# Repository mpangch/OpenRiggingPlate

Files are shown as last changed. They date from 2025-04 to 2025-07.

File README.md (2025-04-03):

# Aluminum Rigging Plate

This repository provides detailed instructions, files, and Finite Element Analysis (FEA) results for manufacturing  the OpenRiggingPlate - a **7075-T6 Aluminium, Hard Anodized Rigging Plate** designed for various rigging applications.

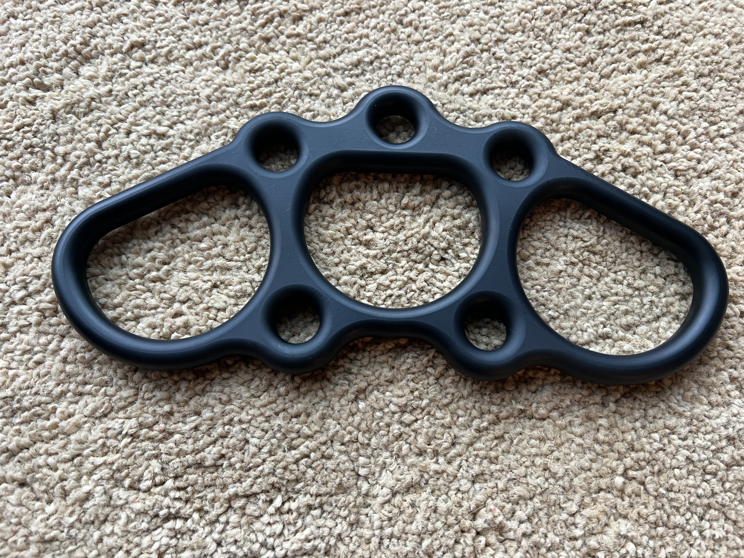
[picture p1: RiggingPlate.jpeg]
OpenRiggingPlate


---

## 📂 Project Files

- **3D Model STEP file**: [`riggingplate-14mar2024.step`](riggingplate-14mar2024.step)  
  *(Ready to upload to CNC services)*

- **SolidWorks Source File**: [`riggingplate-14mar2024.sldprt`](riggingplate-14mar2024.sldprt)  
  *(Modify or customize the design)*

- **Manufacturing Notes PDF**: [`riggingplate-14mar2024-manufacturingnotes.pdf`](riggingplate-14mar2024-manufacturingnotes.pdf)  
  *(Detailed anodizing instructions included—upload this PDF to your machining service.)*

- **Finite Element Analysis**: Refer to the provided `FEA Analysis` folder for detailed results and loading conditions.

---

## 📌 Design Specifications

| Property | Specification |
|---|---|
| **Dimensions** | 235.58 × 111.9 × 12 mm |
| **Material** | Aluminum 7075-T6 (**Do NOT substitute with 6061, as it WILL fail**) |
| **Volume** | 92,450.06 mm³ |
| **Surface Finish**  | CNC machining to **Ra1.6 or better**; hand polishing preferred |
| **Coating** | Hardcoat Anodizing Type III (Default: Black, other colors optional) |
| **Tolerances** | ISO 2768 medium |

---

## 🛠️ How to Manufacture

Follow these step-by-step instructions to have this rigging plate professionally CNC machined:

### **Step 1: Review Files**
- Download all provided files, especially the `.STEP` file for manufacturing and the PDF for anodizing guidelines.

### **Step 2: Choose a CNC Machining Service**
Recommended machining providers:
- [Protolabs](https://www.protolabs.com/)
- [JLCPCB](https://jlcpcb.com/)
- [PCBWay](https://www.pcbway.com/)
- [Xometry](https://www.xometry.com/)
- [Fictiv](https://www.fictiv.com/)

### **Step 3: Upload Files**
- Create an account and log in to your chosen machining service.
- Upload the provided STEP file: `riggingplate-14mar2024.step`.
- **Important:** Upload the PDF file `riggingplate-14mar2024-manufacturingnotes.pdf` with detailed manufacturing and anodizing instructions.

### **Step 4: Specify Material**
- Select **Aluminum 7075-T6** explicitly (critical for safety—6061 WILL fail under load).

### **Step 5: Define Surface Finish**
- Request CNC machining to a minimum surface roughness of **Ra1.6 or better**.
- Specify additional **hand polishing** for a smoother, superior finish.

### **Step 6: Specify Anodizing**
- Select **Type III Hardcoat Anodizing**.
- Default color: **Black** (other colors optional based on preference).
- **Important:** Clearly communicate hanger positions as shown in the provided PDF to minimize visible marks.

### **Step 7: Include Special Instructions**
Copy and paste the following note into the manufacturing special instructions:

> "Please carefully follow the instructions in the provided PDF file (`riggingplate-14mar2024-manufacturingnotes.pdf`) to minimize anodization marks from hanging, restricting marks only to the indicated areas."

### **Step 8: Order & Delivery**
- Confirm all details and submit your order.

---

## 📈 Finite Element Analysis (FEA)

FEA has been thoroughly conducted. The design passed static structural analyses using ANSYS software with remote displacement, allowing rotation about the Z-axis (in and out of page) to simulate realistic load conditions.

### FEA Test Cases and Loading Directions

Refer to the image below to understand each test scenario clearly:

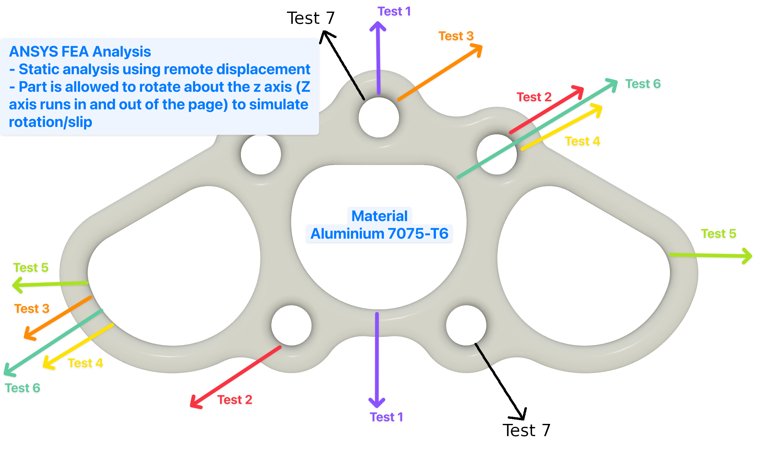
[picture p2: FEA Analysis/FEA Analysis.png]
FEA Analysis


**Minimum Breaking Strength (MBS) Results:**

| Test Case | Direction | Breaking Strength (lbf) |
|---|---|---|
| 1 | Vertical | 2697.7 |
| 2 | Angled horizontal | 2384.5 |
| 3 | Angled horizontal | 4768.8 |
| 4 | Angled horizontal | 2222.5 |
| 5 | Horizontal | 2810.1 |
| 6 | Angled horizontal | 3372.1 |
| 7 | Angled downward | 3034.9 |

Detailed FEA results are available in the `FEA Analysis` folder.

---

## 🚧 Important Notes

- **Material Integrity**: Strict adherence to **7075-T6 aluminum** is required for structural safety. Using weaker materials like 6061 will result in structural failure.
- **Anodizing Hangers**: Carefully follow the instructions in the provided PDF to minimize cosmetic defects from the anodizing process.

---

## 🔧 Modifying the Design

If you wish to customize or adapt the design for specific needs, use the provided SolidWorks source file:

- [`riggingplate-14mar2024.sldprt`](riggingplate-14mar2024.sldprt)

This file allows you to easily modify dimensions, hole positions, or structural features using SolidWorks software.

---

## 📧 Contact

Please open an issue or a pull request on GitHub if you find any errors or have suggestions for improvement.

Happy rigging!

---

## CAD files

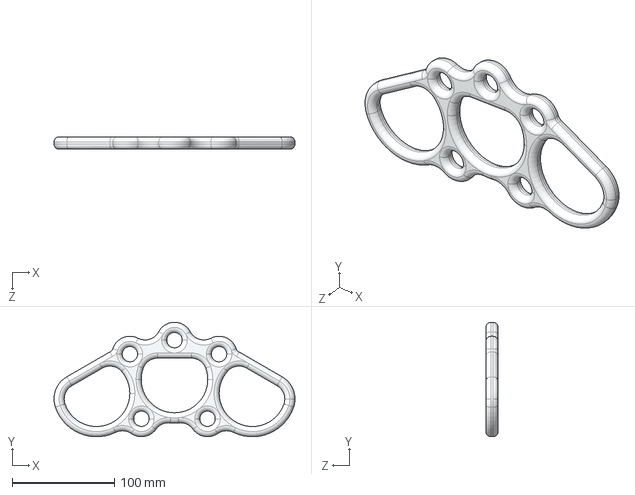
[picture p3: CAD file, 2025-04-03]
riggingplate-14mar2024.step
235.6 x 111.9 x 12.0 mm

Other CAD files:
riggingplate-14mar2024.sldprt

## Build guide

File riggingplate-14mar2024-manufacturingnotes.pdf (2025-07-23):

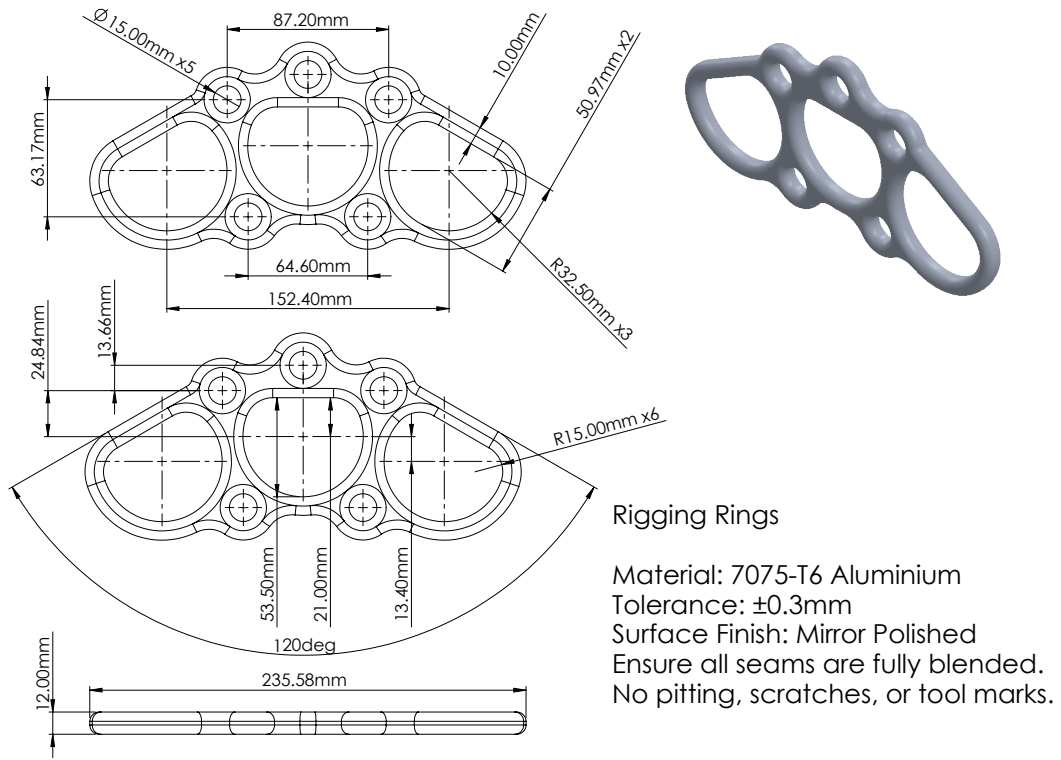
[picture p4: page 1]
120deg

Rigging Rings
Material: 7075-T6 Aluminium
Tolerance: ±0.3mm
Surface Finish: Mirror Polished
Ensure all seams are fully blended.
No pitting, scratches, or tool marks.

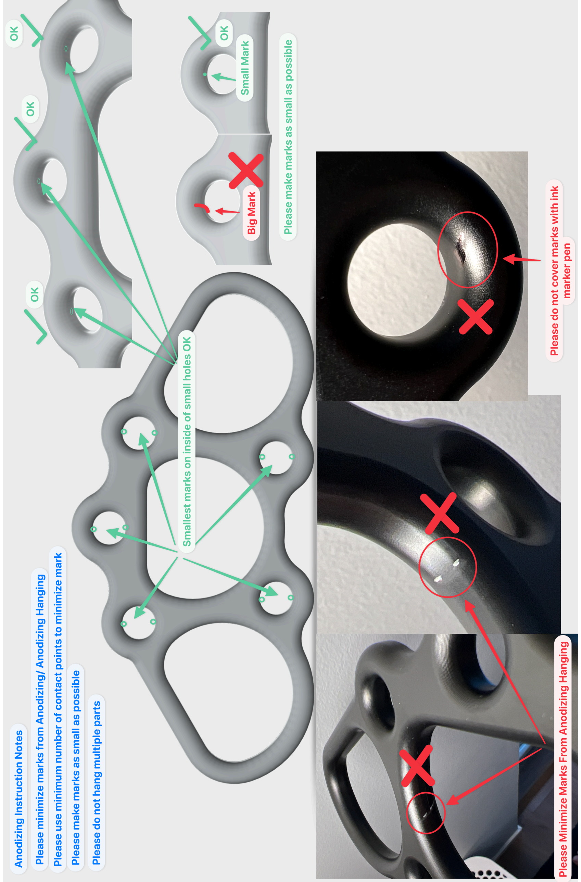
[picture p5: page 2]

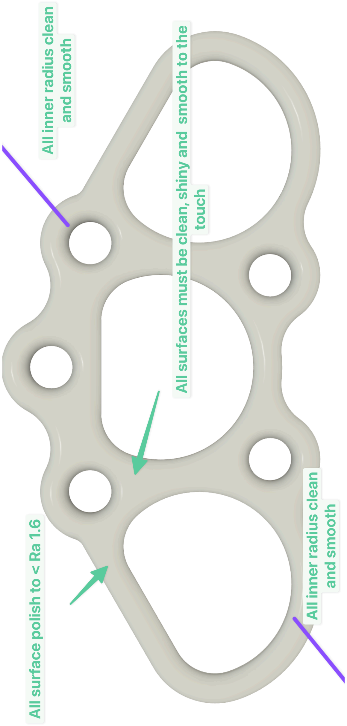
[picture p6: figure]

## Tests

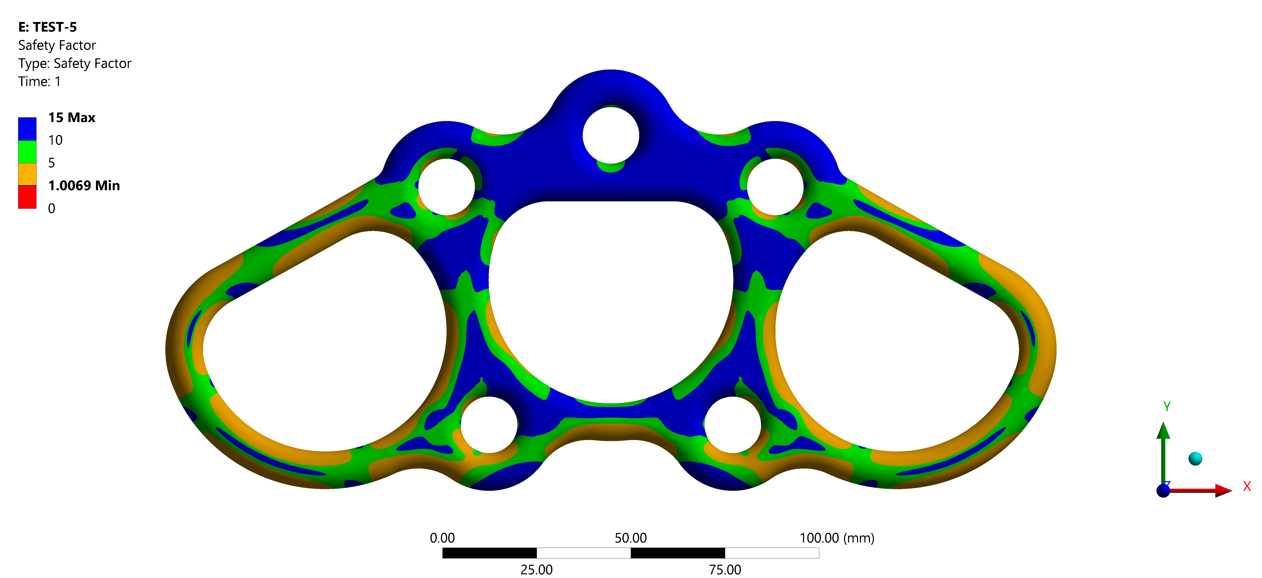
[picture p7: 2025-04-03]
FEA Analysis/Test 5 (2810.1 lbf)/Safety Factor.png

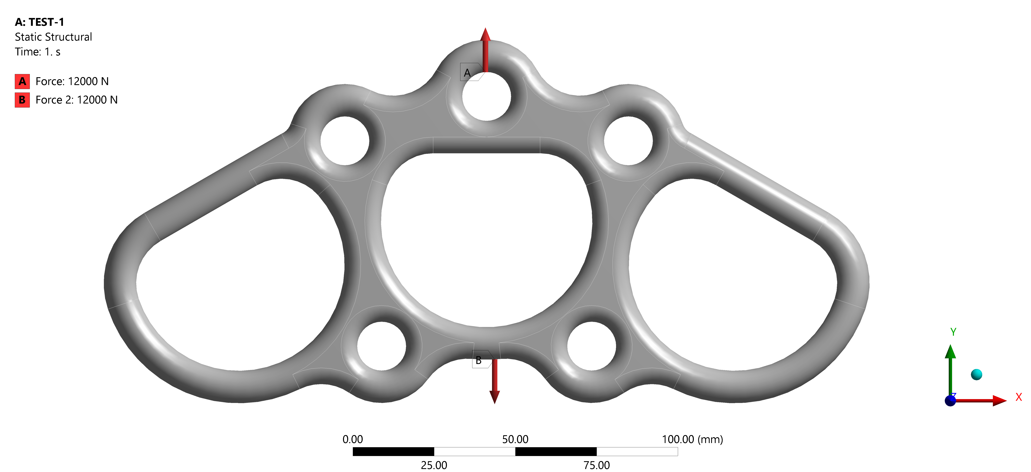
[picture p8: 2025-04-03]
FEA Analysis/Test 1 (2697.7 lbf)/Boundary Conditions.png

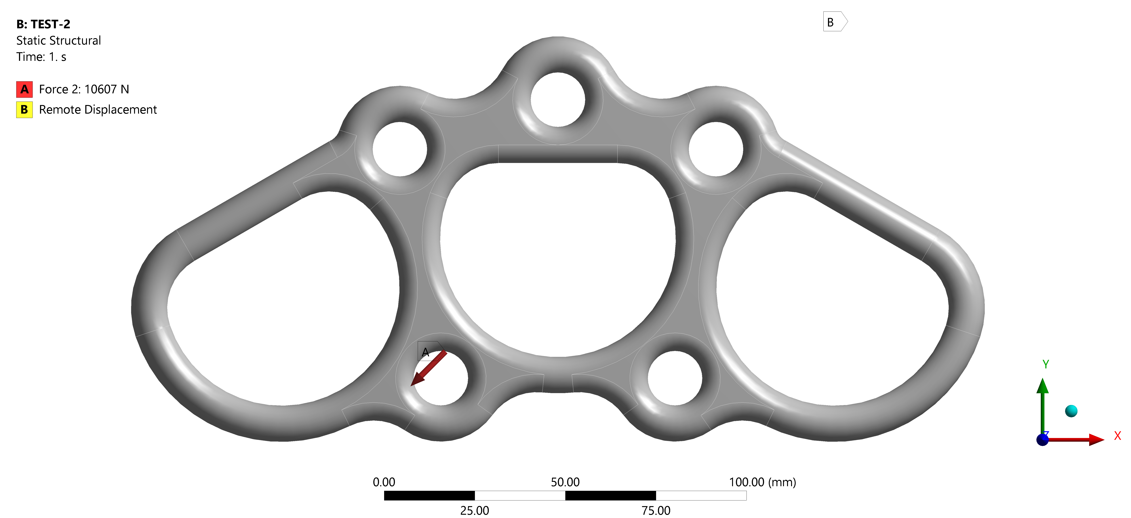
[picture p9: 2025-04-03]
FEA Analysis/Test 2 (2384.5 lbf)/Boundary Conditions.png

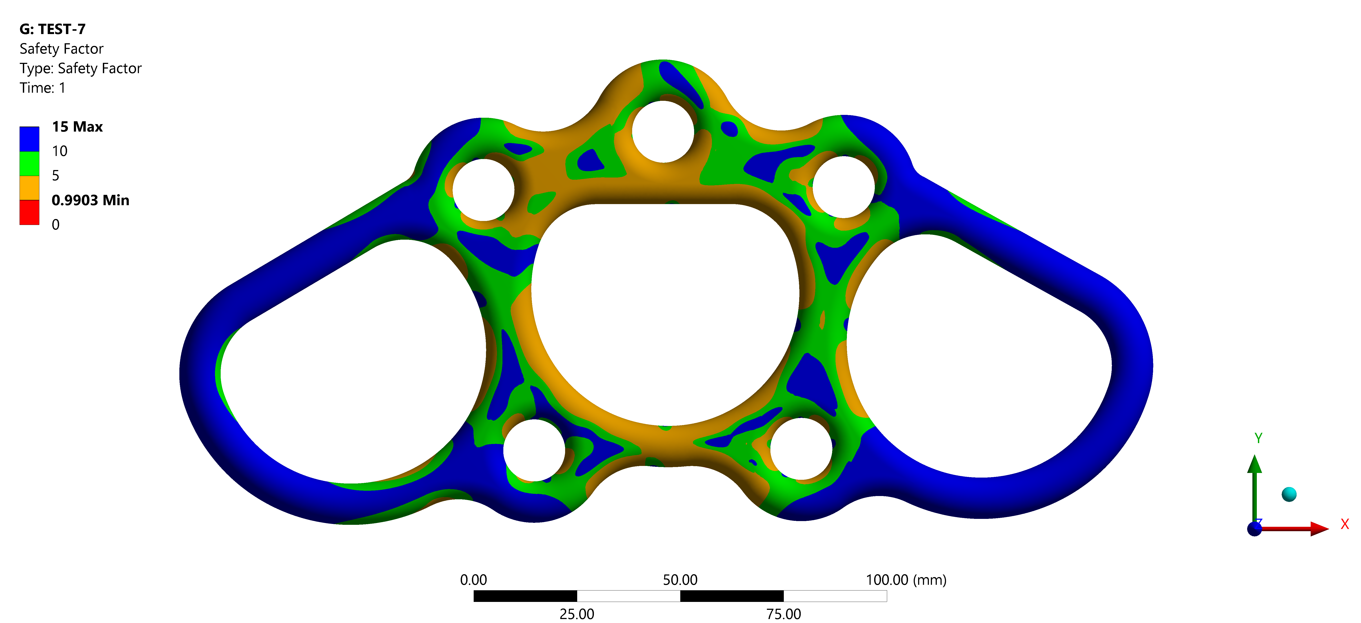
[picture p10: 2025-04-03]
FEA Analysis/Test 7 (3034.9 lbf)/Safety Factor.png

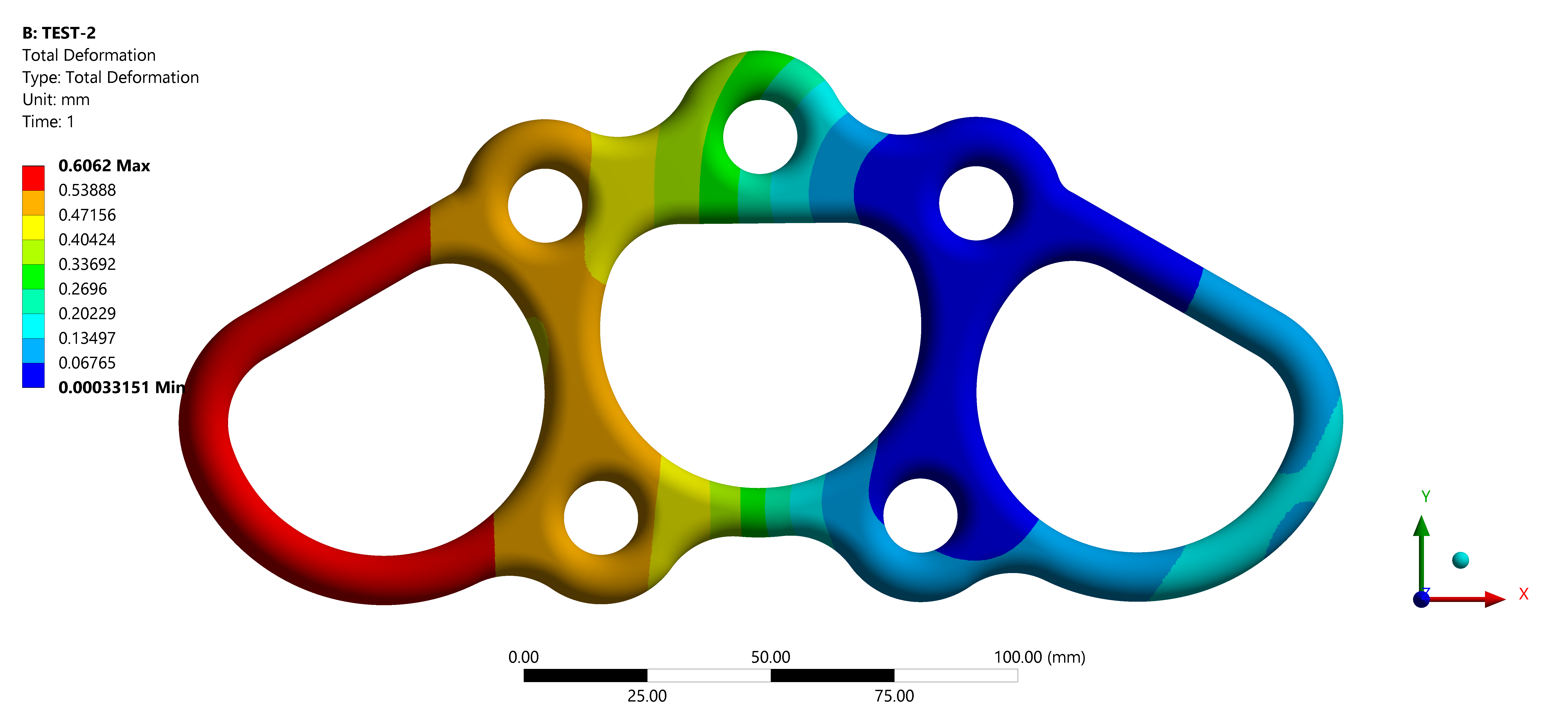
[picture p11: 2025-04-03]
FEA Analysis/Test 2 (2384.5 lbf)/Deformation.png

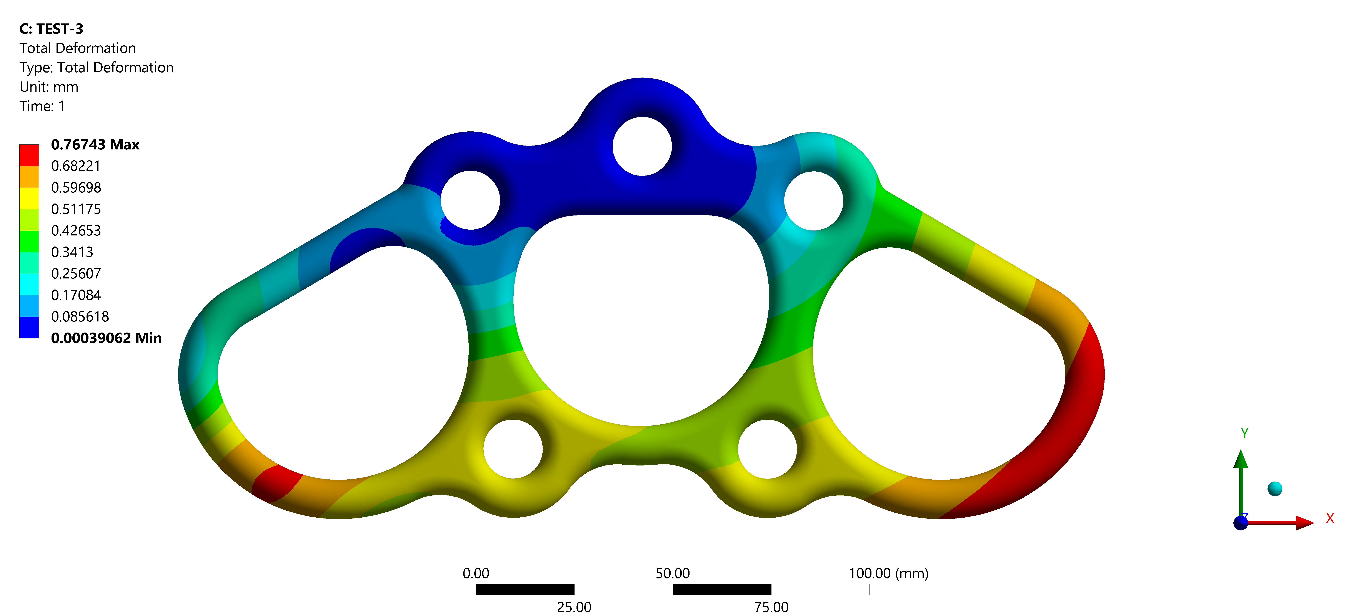
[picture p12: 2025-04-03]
FEA Analysis/Test 3 (4768.8 lbf)/Deformation.png
